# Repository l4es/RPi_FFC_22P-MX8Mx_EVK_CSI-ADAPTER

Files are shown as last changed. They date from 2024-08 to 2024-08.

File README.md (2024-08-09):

# RPi_FFC_22P-MX8Mx_EVK_CSI-ADAPTER

Adapter for Raspberry Pi compatible camera modules to iMX MiniSAS 36-pin camera interface, available in official NXP EVKs.  

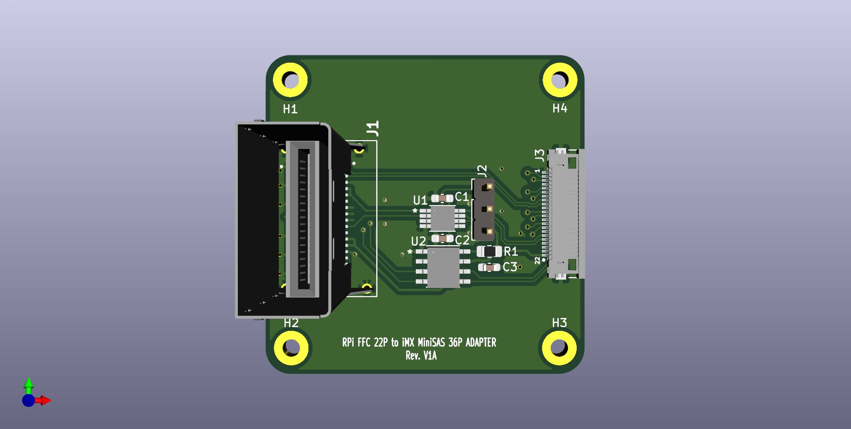
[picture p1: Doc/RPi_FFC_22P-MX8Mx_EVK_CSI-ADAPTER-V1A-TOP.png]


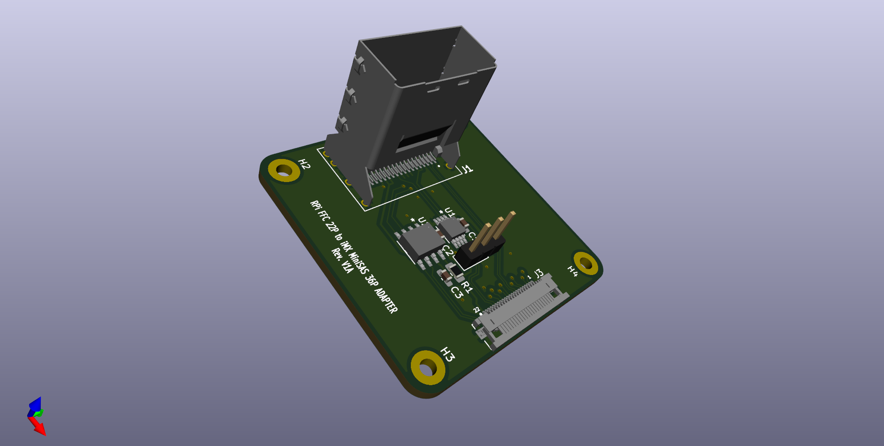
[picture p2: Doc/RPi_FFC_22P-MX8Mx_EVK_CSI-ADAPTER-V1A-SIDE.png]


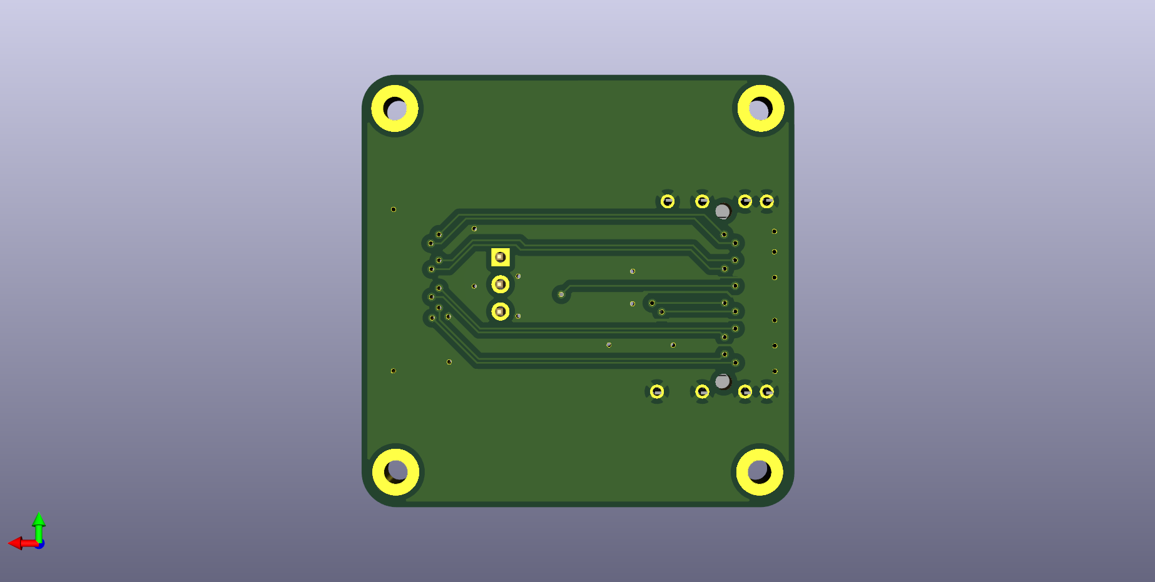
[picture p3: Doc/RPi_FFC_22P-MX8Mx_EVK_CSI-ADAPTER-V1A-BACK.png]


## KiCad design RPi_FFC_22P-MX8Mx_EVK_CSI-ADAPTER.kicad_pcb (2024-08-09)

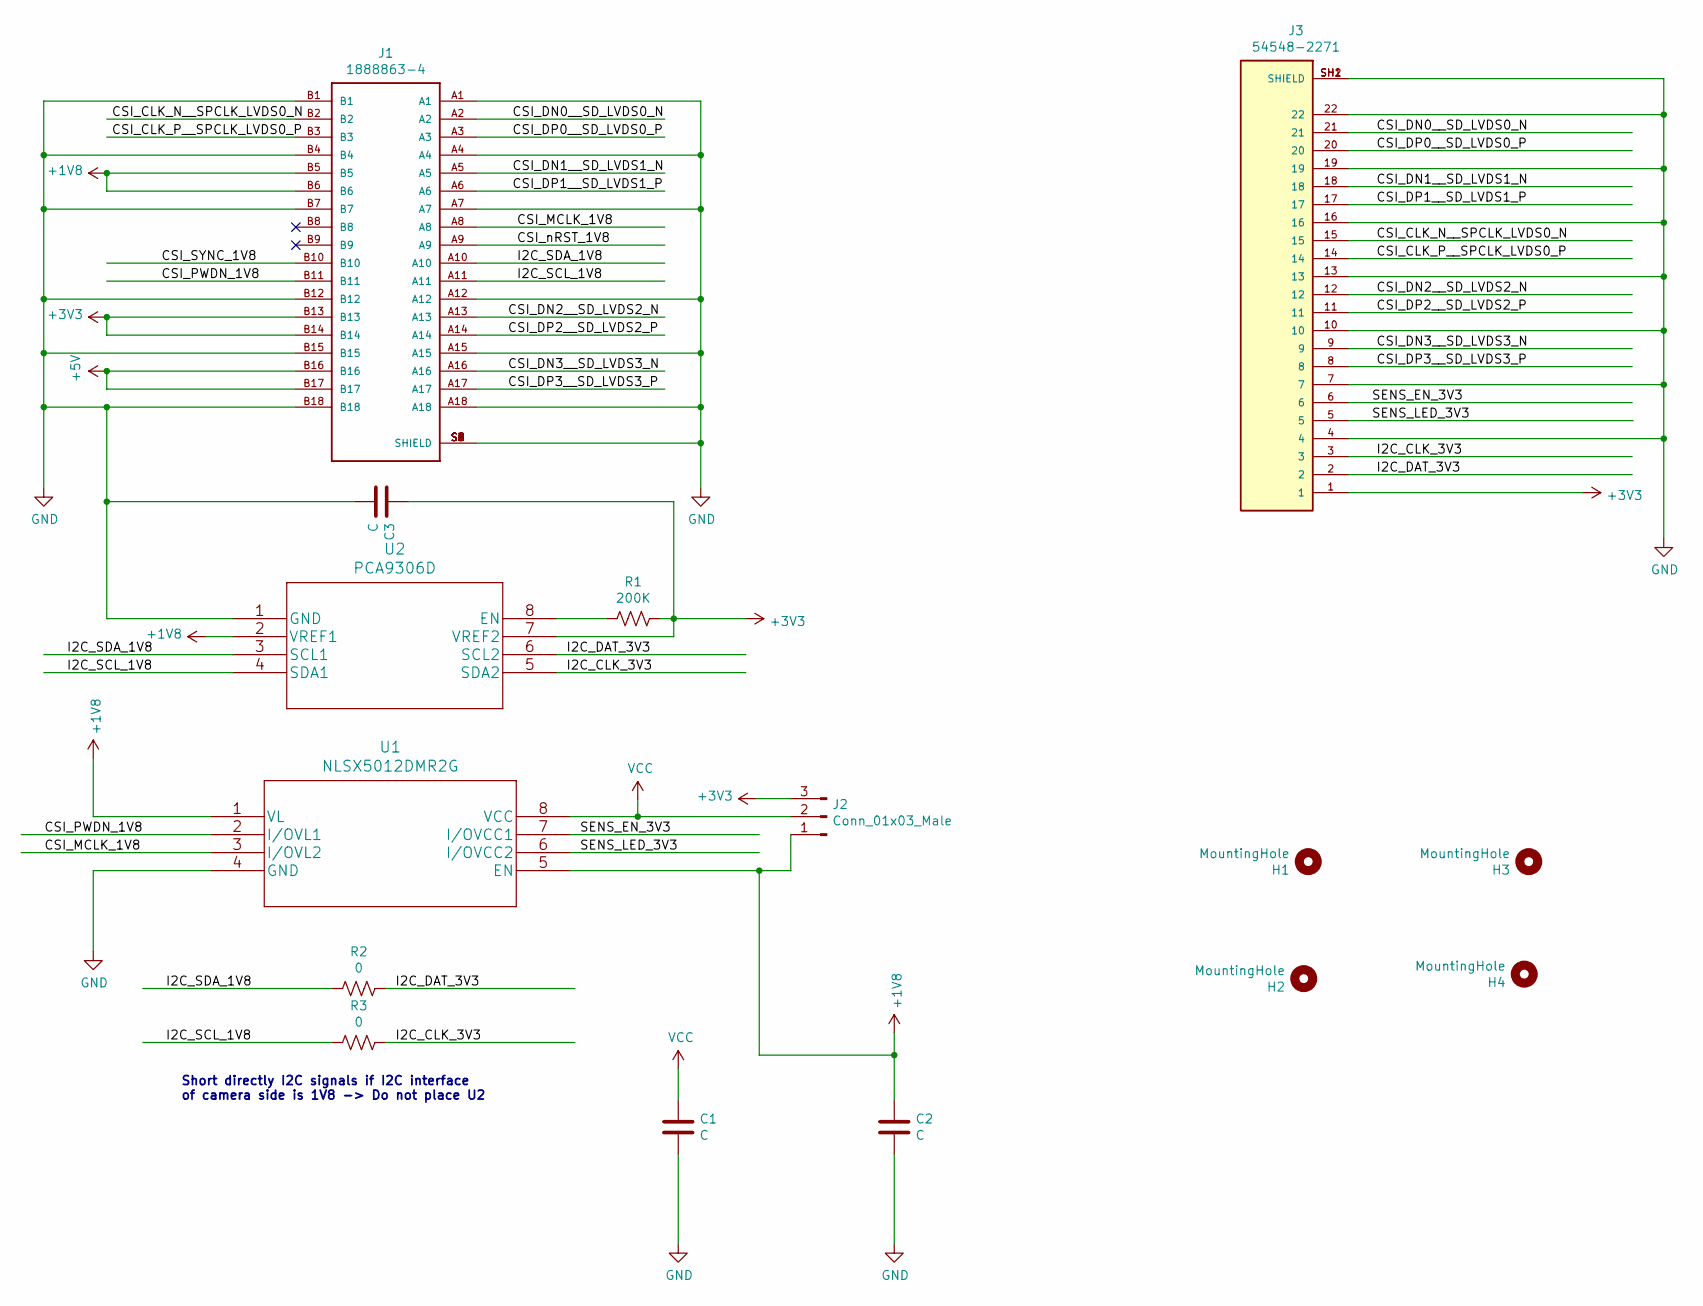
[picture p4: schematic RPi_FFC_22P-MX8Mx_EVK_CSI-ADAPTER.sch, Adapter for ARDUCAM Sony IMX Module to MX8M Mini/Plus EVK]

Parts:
C1, C2, C3: C; C_0603_1608Metric_Pad1.08x0.95mm_HandSolder
H1, H2, H3, H4: MountingHole; MountingHole_2.2mm_M2_Pad
J1: 1888863-4; TE_1888863-4
J2: Conn_01x03_Male; PinHeader_1x03_P2.54mm_Vertical
J3: 54548-2271; MOLEX_54548-2271; PARTREV N
R1: 200K; R_0805_2012Metric_Pad1.20x1.40mm_HandSolder
R2, R3: 0; R_0603_1608Metric_Pad0.98x0.95mm_HandSolder
U1: NLSX5012DMR2G
U2: PCA9306D

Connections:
+1V8: C2.1, J1.B5, J1.B6, J2.1, U1.1 (VL), U1.5 (EN), U2.2 (VREF1)
+3V3: C3.1, J1.B13, J1.B14, J2.3, J3.1, R1.1, U2.7 (VREF2)
+5V: J1.B16, J1.B17
/CSI_CLK_N__SPCLK_LVDS0_N: J1.B2, J3.15
/CSI_CLK_P__SPCLK_LVDS0_P: J1.B3, J3.14
/CSI_DN0__SD_LVDS0_N: J1.A2, J3.21
/CSI_DN1__SD_LVDS1_N: J1.A5, J3.18
/CSI_DN2__SD_LVDS2_N: J1.A13, J3.12
/CSI_DN3__SD_LVDS3_N: J1.A16, J3.9
/CSI_DP0__SD_LVDS0_P: J1.A3, J3.20
/CSI_DP1__SD_LVDS1_P: J1.A6, J3.17
/CSI_DP2__SD_LVDS2_P: J1.A14, J3.11
/CSI_DP3__SD_LVDS3_P: J1.A17, J3.8
/CSI_MCLK_1V8: J1.A8, U1.3 (I/OVL2)
/CSI_PWDN_1V8: J1.B11, U1.2 (I/OVL1)
/CSI_SYNC_1V8: J1.B10
/CSI_nRST_1V8: J1.A9
/I2C_CLK_3V3: J3.3, R3.1, U2.5 (SDA2)
/I2C_DAT_3V3: J3.2, R2.1, U2.6 (SCL2)
/I2C_SCL_1V8: J1.A11, R3.2, U2.4 (SDA1)
/I2C_SDA_1V8: J1.A10, R2.2, U2.3 (SCL1)
/SENS_EN_3V3: J3.6, U1.7 (I/OVCC1)
/SENS_LED_3V3: J3.5, U1.6 (I/OVCC2)
GND: C1.2, C2.2, C3.2, J1.A1, J1.A4, J1.A7, J1.A12, J1.A15, J1.A18, J1.B1, J1.B4, J1.B7, J1.B12, J1.B15, J1.B18, J1.S1 (SHIELD), J1.S2 (SHIELD), J1.S3 (SHIELD), J1.S4 (SHIELD), J1.S5 (SHIELD), J1.S6 (SHIELD), J1.S7 (SHIELD), J1.S8 (SHIELD), J3.4, J3.7, J3.10, J3.13, J3.16, J3.19, J3.22, J3.SH1 (SHIELD), J3.SH2 (SHIELD), U1.4 (GND), U2.1 (GND)
unnamed: R1.2, U2.8 (EN)
VCC: C1.1, J2.2, U1.8 (VCC)

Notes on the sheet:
Short directly I2C signals if I2C interface of camera side is 1V8 -> Do not place U2

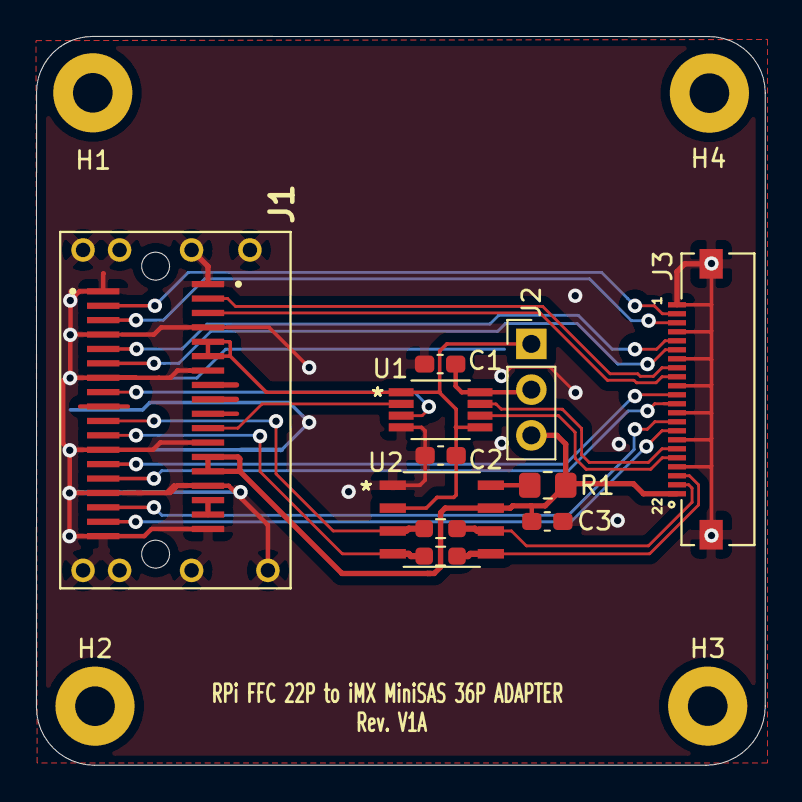
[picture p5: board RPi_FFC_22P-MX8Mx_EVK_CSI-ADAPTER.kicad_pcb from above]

Board: 2 copper layers, 40.5 x 40.5 mm, 15 parts (0 on the bottom side), 24 nets.

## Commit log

2024-08-09 Add V1A revision
    [RPi_FFC_22P-MX8Mx_EVK_CSI-ADAPTER.kicad_pcb, RPi_FFC_22P-MX8Mx_EVK_CSI-ADAPTER.sch]
2024-08-09 Update documentation to show board's images

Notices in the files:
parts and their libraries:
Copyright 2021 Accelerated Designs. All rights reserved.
